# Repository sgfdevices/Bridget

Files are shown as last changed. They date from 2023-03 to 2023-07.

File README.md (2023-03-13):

# Bridget
3D Printable Files for SGF Bridget controller. The case is a modified version of the Flatbox rev4 by jfedor (https://github.com/jfedor2/flatbox). The buttons are a modified version of the Egg On Rice buttons by b1nc (https://github.com/b1nc/Egg-On-Rice-Controller). It is designed to fit a Flatbox rev4 PCB without modification.  
  
v1 of this case is no longer used. v2 was developed to increase rigidity, ease assembly, and allow for future additions. When assembling v2, tolerances are tight and may require a SMALL amount of pressure to seat the sides into other pieces. If the pieces do not snap together with small amounts of force, your printer/filament may need tuning to print the dimensions more accurately, or you may need to do some sanding. You can also always go back to printing v1.  
  
Each case requires the following for full assembly:  
1x top case  
1x bottom case  
2x sides - IMPORTANT NOTE - the portion of the side panel that seats into the top case is deeper than the portion that seats into the bottom case. If your case doesn't close without a gap, you probably have the side panel upside down.  
11x small button  
1x big button  
7x M2x3 or M2x4 heat set brass inserts (https://amazon.com/gp/product/B0B8GN63S2)  
7x M2x5 or M2x6 countersunk flat screws (https://amazon.com/gp/product/B0B54FHHDW)  
4x 6mm/0.25in bumpons (https://amazon.com/dp/B016GWHSBE)  
  
All parts can be printed without supports. You may or may not need a brim for the larger case pieces depending on how good your filament's bed adhesion is. Use the ideal layer height for your printer. For our production runs, these are printed with default Optimal settings for our printers in Bambu Lab. Use of a fast CoreXY printer like a Voron or Bambu is advised if you'd like to make them regularly, as they can take quite a while to print.

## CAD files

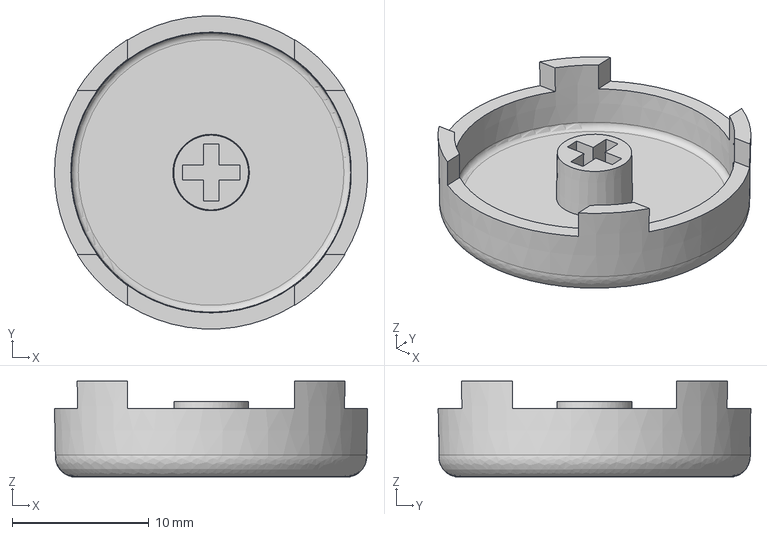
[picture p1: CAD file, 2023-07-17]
Buttons/mx_cap_small.step
22.9 x 22.9 x 7.00 mm

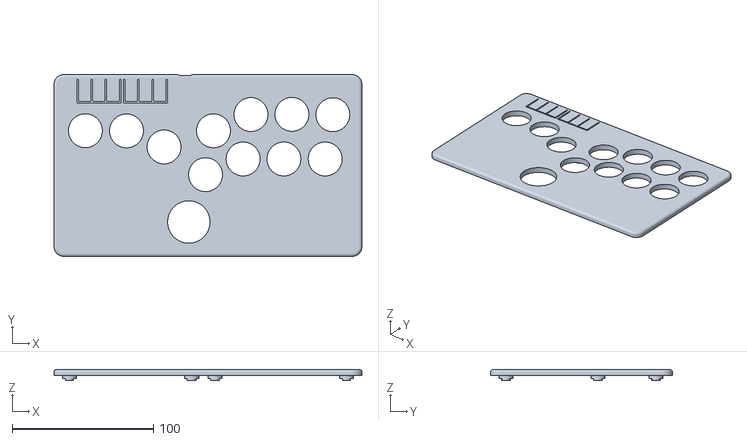
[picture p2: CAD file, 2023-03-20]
Rev 5 Case -- UNTESTED/top.stl
218.0 x 128.7 x 8.10

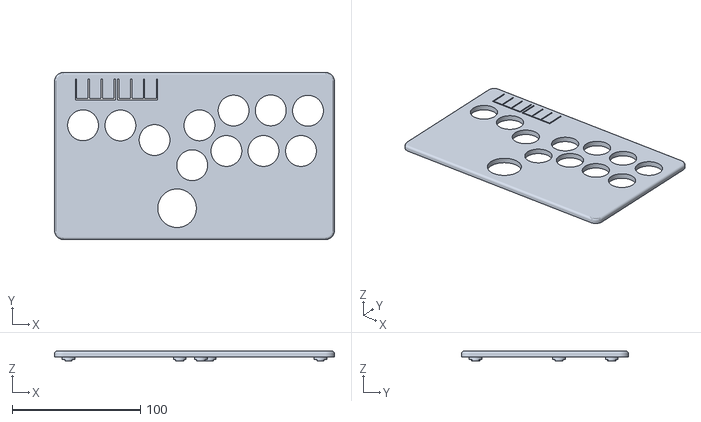
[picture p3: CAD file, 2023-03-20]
v2/top.stl
218.0 x 130.1 x 7.70

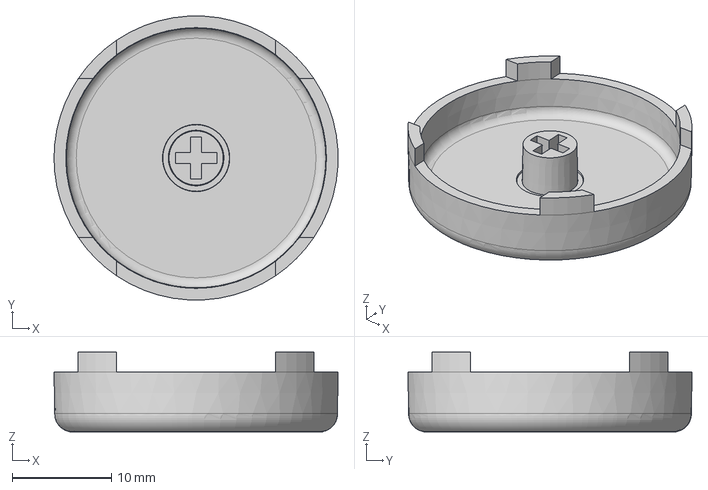
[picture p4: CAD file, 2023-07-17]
Buttons/mx_cap_large.step
28.6 x 28.6 x 8.02 mm

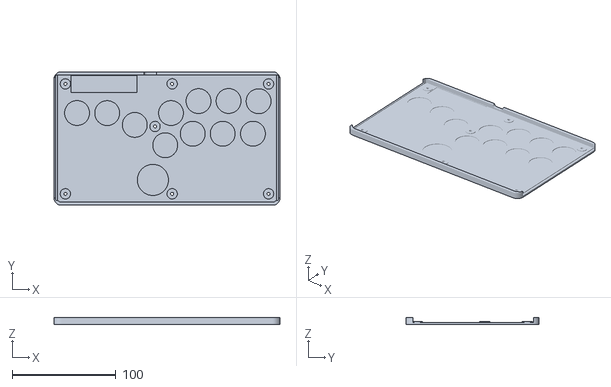
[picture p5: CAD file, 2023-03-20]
Rev 5 Case -- UNTESTED/btm.stl
218.0 x 128.7 x 6.30

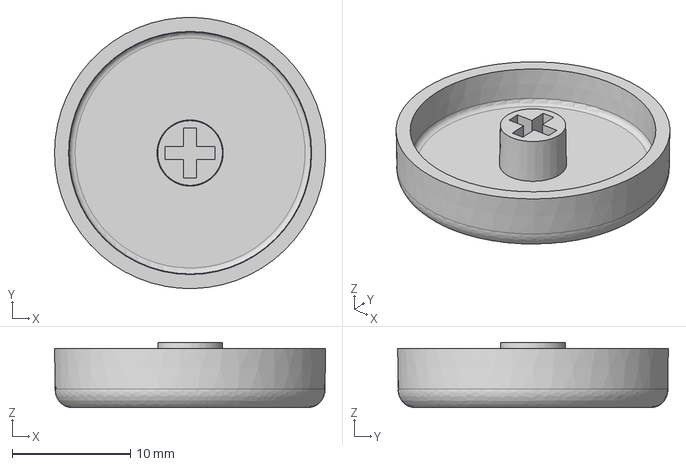
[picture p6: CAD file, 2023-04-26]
Buttons/small mx cap.step
22.9 x 22.9 x 5.50 mm

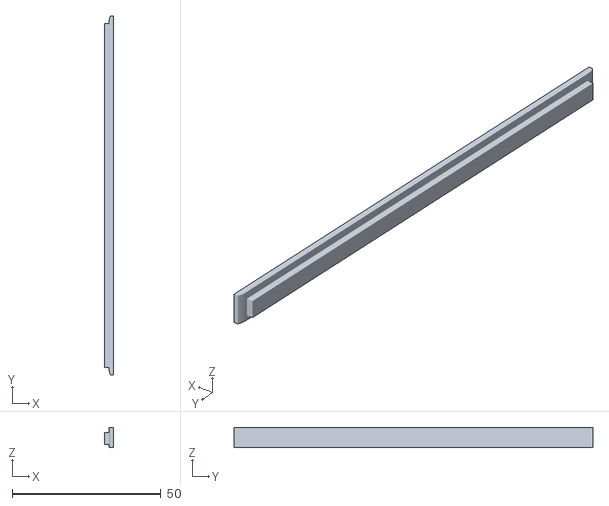
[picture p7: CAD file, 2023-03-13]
Rev 5 Case -- UNTESTED/side.stl
3.00 x 120.6 x 6.80

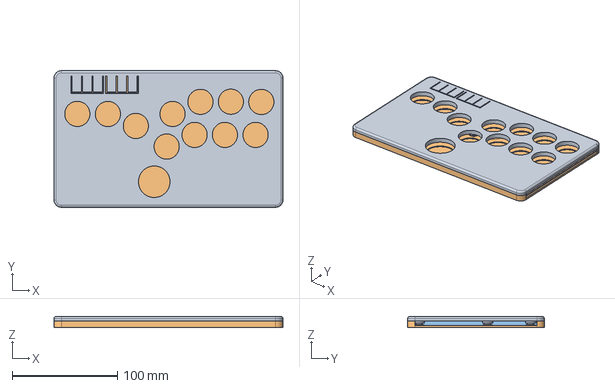
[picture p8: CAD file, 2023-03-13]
v2/bridgetv2.step
218.0 x 130.1 x 10.8 mm

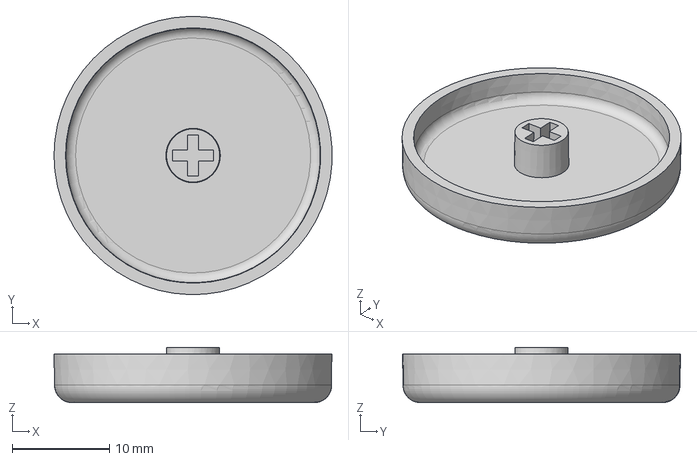
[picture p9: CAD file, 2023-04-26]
Buttons/large mx cap.step
28.6 x 28.6 x 5.69 mm

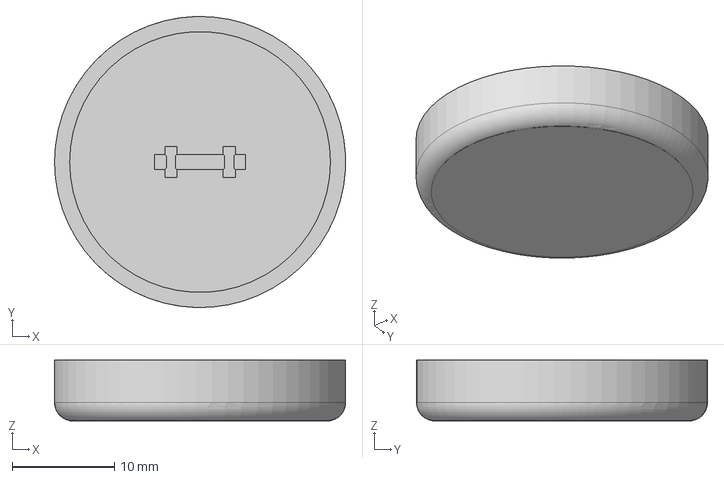
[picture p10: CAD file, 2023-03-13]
Buttons/button_large.step
28.5 x 28.5 x 5.94 mm

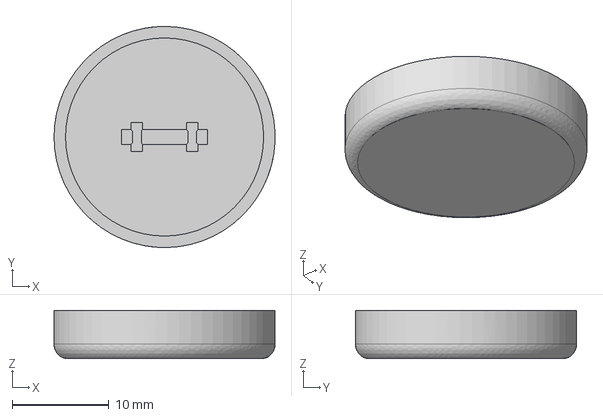
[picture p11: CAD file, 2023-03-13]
Buttons/button_small.step
22.8 x 22.8 x 5.00 mm

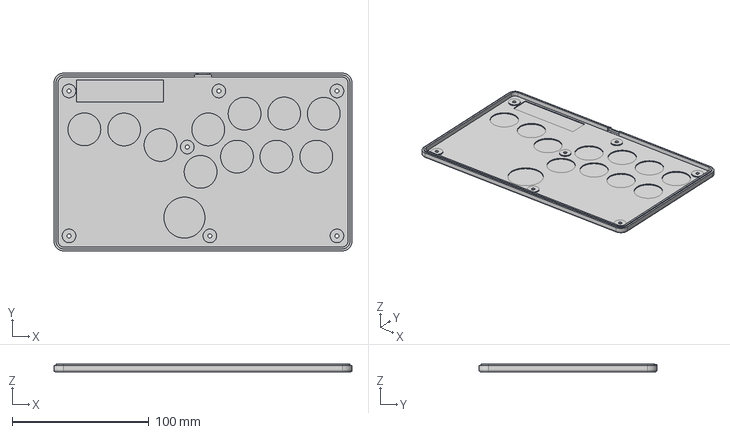
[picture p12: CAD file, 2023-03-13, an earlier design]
v1/bottom_case.step
218.0 x 130.1 x 5.70 mm

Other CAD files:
v2/btm.stl
v2/sidestl.stl
Buttons/small_button.stl
Buttons/button_large.stl
Buttons/deprecated versions/v1 stems/button_large.stl
Buttons/deprecated versions/v1 stems/small_button.stl
Buttons/deprecated versions/v2 stems/large mx cap.stl
Buttons/deprecated versions/v2 stems/small mx cap.stl
Buttons/large mx cap.stl
Buttons/small mx cap.stl
v1/bottom_case.stl
v1/top_case.step
v1/top_case.stl

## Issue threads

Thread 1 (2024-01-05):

3D Print for new "Screwless" design

Still-Icarus, 2024-01-05:
I just recently bought an Sgf Bridget that came with it's new screw-less design. I was planning on printing a custom case for it but only models that use screws are featured here. Are there any plans to upload the screw-less case to github, or did i miss it somewhere?

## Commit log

2023-02-11 Adding .stl for printable parts
    [big_button.stl, bottom_case.stl, small_button.stl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]
2023-02-11 Added .step files
    [bottom_case.step, button_large.step, button_small.step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]
2023-03-13 adding v2, reorganizing
    [bottom_case.step, bottom_case.stl, bridgetv2.step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]
2023-03-13 adding UNTESTED rev5 case design
    [btm.stl, side.stl, top.stl]
2023-03-16 fixed mesh on v2 top
    [top.stl]
2023-03-18 updated r2 top for clearance
    reduced size of corner locating pins for PCB in order to have wider tolerance for PCB variation and allow for more flatness
    [top.stl]
2023-03-19 updated r5 case to expose more of the USB port
    [btm.stl, top.stl]
2023-03-20 r5: increased USB hole size. r4v2: increased tolerance for side skirts on top case
    [btm.stl, top.stl]
2023-03-20 r5: increased usb cutout just a bit more
    [btm.stl, top.stl]
2023-04-26 adding mx buttoncaps
    adding mx-compatible button caps for anyone using choc v2 switches
    [large mx cap.step, small mx cap.step]
2023-06-19 adding MX cap STLs
    [large mx cap.stl, small mx cap.stl]
2023-07-17 reorganized button files, added updated cap design
    [button_large.step, button_large.stl, button_small.step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]
